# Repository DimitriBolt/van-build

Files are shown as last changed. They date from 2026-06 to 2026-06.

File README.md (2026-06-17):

# van-build — CAD-каркас салона RAM ProMaster 1500 136" High Roof

Параметрическая **каркасная** модель салона кемпера на базе RAM ProMaster 1500
(колёсная база 136", высокая крыша; кузовной близнец — Fiat Ducato L2H2), построенная
во FreeCAD по 3D-скану реального кузова.

## Подход

- **CAD = только каркас** (к нему крепится оборудование). Обшивку в CAD не моделируем.
- **Обшивка = сам 3D-скан** кузова (меш), полупрозрачный, лежит поверх каркаса.
- Внутренний объём — не «коробка», а **сложная форма, снятая со скана**: гнутые борта,
  скруглённое плечо, округлая крыша. Рёбра каркаса — гнутые обручи по контуру скана.

Так совмещаются визуальное сходство (скан) и проектопригодная CAD-геометрия (каркас).

## Система координат

Ноль — пол у порога **задних** дверей, на центральной оси.
`X` = длина (0 сзади, +X к кабине); `Y` = ширина (0 центр, +Y пассажир); `Z` = высота (0 пол).

## Файлы

| Файл | Что это |
|---|---|
| `van_v0.py` | Скрипт-генератор модели (правишь `PARAMS` → пересобираешь) |
| `freecad_rpc.py` | Клиент к живому FreeCAD GUI (`van_rpc_server.FCMacro` на `127.0.0.1:9875`) |
| `van_v0.FCStd` | Собранный документ FreeCAD (каркас + меш-обшивка) |
| `Ducato_L2H2_body_reference.stl` | Чистая наружная оболочка кузова (нужна скрипту) |
| `Ducato+L2H2+lit+superpose2.stl` | Плотный скан целиком (с мебелью/человеком) |
| `Ducato+L2H2+lit+superpose2.skp` | Исходная SketchUp-модель |
| `PROJECT_MEMORY.md` | Сводная память по всему проекту (электрика, кузов, 3D и т.д.) |

## Сборка

Headless:

```bash
~/Applications/FreeCAD.AppImage --console ~/van-build/van_v0.py
```

Скрипт измеряет профиль борта из `Ducato_L2H2_body_reference.stl`, строит каркас,
кладёт скан как обшивку и сохраняет `van_v0.FCStd`.

## Статус

Габариты оболочки и форма свода **измерены по скану**. Точные позиции рёбер, проёмов
дверей и колёсных арок — пока SEED-заглушки; заменяются на реальные значения
после ручного промера фургона (см. раздел про промерку в `PROJECT_MEMORY.md`).

Сторона сдвижной двери задаётся параметром `slider_side` в `van_v0.py`
(`-1` = левый/driver борт `-Y`, `+1` = passenger борт `+Y`); текущая
оценка проёма — `1250 × 1755 мм`.

Текущая модель использует 3 основных гнутых обруча: задняя рама, смещённая внутрь обшивки на X=160, задняя/средняя
рама сдвижной двери и передняя рама сдвижной двери у кабины (`X=1880..3130`, по STL-окну сдвижной двери). Обручи красные,
продольные рейки синие; задняя распашная дверь показана двумя половинками.

Продольные рейки: верхняя поднята до `Z=1700`, средняя оставлена `Z=980`; нижняя `Z=20` показана как низовая крепёжная рейка, касающаяся пола (`Z=0..40`) и разрывается на зоне колёсных арок `X≈520..1650` и сдвижной двери.
Заводские резьбовые точки показаны отдельным слоем `FactoryThreadedMounts`: 3 точки на длинной `pY` рейке `Z=980`, 2 точки на короткой `nY` рейке `Z=980`; текущая память о резьбе — `M8/M10`, надо уточнить промером.

Поперечины пола удалены: в модели вместо них показан рефлёный металлический пол
`CorrugatedFloor` с продольными гребнями вдоль фургона.

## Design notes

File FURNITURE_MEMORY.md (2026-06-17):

# FURNITURE MEMORY — Мебель и подвес оборудования (RAM ProMaster 136 HR)

_Отдельная память по этапу проектирования мебели/крепежа, чтобы не раздувать
`PROJECT_MEMORY.md`. Технические термины/пути — на английском, остальное по-русски.
Источник правды по геометрии кузова — `van_v0.py` / `van_v0.FCStd` (см. `PROJECT_MEMORY.md` §5).
Последнее обновление: 2026-06-17._

---

## 0. Общие принципы этапа
- **Материал каркаса — strut channel (Unistrut/Superstrut/Newhouse)**, покупка Home Depot/Lowe's.
- **БЕЗ СВАРКИ.** Сборка только на fittings: угловые кронштейны 90°, channel nuts (пружинные
  гайки в паз), болты. **Разборная/демонтируемая** — обязательно.
- **Цена важна.** Главное удешевление (2026-06-17): **весь каркас из НЕГЛУБОКОГО профиля**
  (он дешевле всего), а поперечные лаги — из **бесплатных деревянных 2×4** Dimitri.
- Dimitri может **резать strut, сверлить доп. отверстия, нарезать резьбу.**
- Профиль strut: **Неглубокий 1-5/8″×13/16″** (≈41.3×21 мм, 14 ga), сток **10 ft (3048 мм)**.
  ⚠️ Ширина паза 1-5/8″ у неглубокого и глубокого ОДИНАКОВА → **фитинги одни и те же**
  (отличается только глубина спинки). Брать неглубокие фитинги не обязательно — подходят любые.

## 1. Кровать (КАРКАС в `van_v0.py`, группа `Bed_StrutFrame`)
**Тип:** поперечная (спим ПОПЕРЁК фургона), в задней части.
- **ДЛИНА кровати** (вдоль Y, спальное место) = борт↔борт ≈ **1879 мм** (со скана через `y_at_z`).
- **ШИРИНА кровати** (вдоль X, от задних дверей вперёд) — `BED["mattress_width_x"]`,
  **1400 по умолчанию; 1200 — альтернатива.** ⚠️ При **1200** фанера влезает в ОДИН лист
  4×8 (ширина листа 1220 мм) → экономия целого листа. При 1400 нужно 2 листа.
- Верх несущей рамы `BED["top_z"] = 980` ≈ высота заводских резьбовых точек. Под кроватью
  сквозной «гараж» ~0.94 м.

**СХЕМА (удешевлённая, 2026-06-17) — «4 ноги + 2 продольные strut + 2×4-лаги»:**
- **4 ноги-стойки** — неглубокий strut, болтятся к борту в ЗАВОДСКИХ резьбовых точках
  (`FactoryThreadedMounts`, Z=980, резьба **M8/M10 — уточнить на живом фургоне**):
  `pY`/`nY` @ **X=360** (`rear_thread_x`) и `pY`/`nY` @ **X=1680** (`middle_thread_x`).
  Идут от пола Z=0 вверх до **Z≈1330** (плечо крыши) — служат направляющими под обшивку.
  Высота ноги ~1330 < 1524 (5 ft) → **2 ноги выходят из одного 10-ft хлыста**.
- **2 продольные несущие** (вдоль X, Y=±940) — куски **5 ft (1520 мм)**, передним краем к
  X=1720, перекрывают обе ноги; **2 шт из одного 10-ft хлыста** (раскрой 10ft→2×5ft).
- **4 поперечные лаги 2×4** (дерево, БЕСПЛАТНО) — лежат на продольных рейках, на них фанера.
  ⚠️ Пролёт лаги между рейками ~1.8 м: 2×4 **плашмя** может прогибаться. Если просядет —
  поставить 2×4 **на ребро** (89 мм по высоте) или добавить центральную балку. См. §3.
- **Настил — фанера 1/2″** (дешевле 3/4″) на лагах; задний край свешивается ~180 мм за рейку
  (консоль фанеры — нормально, опор не нужно). Матрас — **поролон, режется по форме**.
- **РАСКРОЙ strut: ровно 3 хлыста ×10ft = 4 ноги (2 шт/хлыст ×2) + 2 продольные (1 хлыст).**

**Что УБРАЛИ при удешевлении (2026-06-17):**
- 5-я стойка под оборудование (`equip_post=False`) — ОТЛОЖЕНА (не входит в 3 хлыста; вернуть = `True`).
- Задние опорные ножки на полу — не нужны (свес фанеры всего ~180 мм).
- Глубокий профиль и неглубокие поперечины strut — заменены неглубоким каркасом + 2×4.

**РЕШЕНО ранее (2026-06-16): стойки обрезаются на плече крыши ≈ Z=1330, до потолка НЕ ведём**
(прямой вертикальный strut на Y≈940 выше Z≈1330 вышел бы наружу сквозь скан — крыша
заворачивает внутрь). `post_top` считается авто как макс. Z, где `y_at_z(z) >= yL`.

**Смета — см. §4. Текущая оценка ~$165** (strut $69 + крепёж $32 + фанера+саморезы $64,
цена за единицу). В магазине наборами/упаковками — реально **~$190–200** (или ~$170 при ширине
1200 / 1 лист; ~$140 если настил из своих 2×4 без фанеры). Без поролона.

**Совместимость с проёмами:** кровать целиком ПОЗАДИ сдвижной двери; ноги X=360/1680 не в
проёмах. Под кроватью загрузка через задние двери.

## 2. Где это в коде
- `van_v0.py`: `BED = {...}` и `BED_PRICES = {...}` под `PARAMS`; построение — секция
  «КРОВАТЬ — каркас из strut channel» в `build()` (группа `Bed_StrutFrame`); смета печатается
  в сводке. Цвета: `COL_STRUT` (сталь), `COL_PLY` (фанера), `COL_WOOD` (2×4), `COL_MATTRESS`.
- Объекты: `BedLeg_*` (4 ноги), `BedRailLong_*` (2 продольные), `BedJoist2x4_*` (4 лаги),
  `BedDeck_Plywood`, `BedMattress`.
- Пересборка headless: `~/Applications/FreeCAD.AppImage --console ~/van-build/van_v0.py`.
  Цвета/рендер — только пересборкой в живом GUI через RPC (см. [[freecad-snap-live-control]]).
- Параметры под изменение: ширина `mattress_width_x` (1400↔1200), `n_joist`, `deck_th`,
  `equip_post`, `rail_len`.

## 3. Открытые вопросы / ждёт живого фургона
- [ ] Решить ширину кровати вдоль X: **1200 (1 лист фанеры, дешевле)** или **1400**.
- [ ] Уточнить заводскую резьбу в точках Z=980: **M8 или M10**, и реальные X/Z точек.
- [ ] **Проверить прогиб лаг 2×4 плашмя на пролёте ~1.8 м** под спальной нагрузкой.
      Если есть прогиб: (а) 2×4 на ребро, (б) больше лаг, (в) центральная продольная балка
      на 2 напольных стойках. Дерево бесплатное → дёшево усилить.
- [ ] Финальный замер длины борт↔борт и высоты ноги на живом фургоне → подрезка.

---

## 4. СПИСОК ПОКУПОК (BOM) — открой в магазине, ничего не забудь
_Цены США, июнь 2026 (проверять при заказе). Можно из РАЗНЫХ магазинов. Поролон НЕ входит._
_Считается на ширину 1400 мм (2 листа фанеры). Для 1200 мм — 1 лист (−$28)._

### A. Strut channel — Home Depot (самовывоз; длинномер дорого слать)
- [ ] **Неглубокий strut 1-5/8″×13/16″ 14ga 10 ft** — Newhouse **SC14-10-EG**, **$23/шт × 3 = $69**.
  - Раскрой: хлыст №1 → 2 ноги (~1330 мм); хлыст №2 → 2 ноги; хлыст №3 → 2 продольные (1520 мм).

### B. Фитинги (Amazon оптом дешевле; берём упаковками)
- [ ] **Уголок 90° для strut (2-отв.)** — нужно **4 шт**. Мультипак ~$12–15.
- [ ] **Пружинная гайка + болт 1/2″-13 (channel nut + bolt)** — нужно **~16 компл.**
  Брать **набор 50 шт ~$30–40** (хватит с запасом на оборудование позже).
- [ ] **Болт в заводскую резьбовую точку борта (M8 или M10 — уточнить!)** — **4 шт**, ~$5.
- [ ] **Заглушки на торцы strut** — **~12 шт**, пакет 25 ~$8.

### C. Дерево — БЕСПЛАТНО (из запасов Dimitri)
- [ ] **2×4 длиной ~1.9 м — 4 шт** (поперечные лаги под фанеру). $0.

### D. Настил
- [ ] **Фанера 1/2″ 4×8 ft** — CDX ~$28/лист (OSB ~$18 ещё дешевле).
  **2 листа** при ширине 1400 = ~$56. **1 лист** при ширине 1200 = ~$28.
  ⚠️ Альтернатива «настил из 2×4-реек» (свои, $0) — фанера не нужна вообще, минус ~$56.
- [ ] **Саморезы по дереву (коробка)** ~$8.

### E. Поролон (отдельно, режет сам) — НЕ в этой смете
- [ ] Поролон под матрас ~$80–150 (Amazon/магазин поролона), режется по форме.

### ИТОГ (без поролона)
| Вариант | Цена |
|---|---|
| Базовый (ширина 1400, фанера 2 листа) | **~$190–200** |
| Ширина **1200** (фанера 1 лист) | **~$165–175** |
| Настил из своих 2×4-реек (без фанеры), ширина 1200 | **~$140** |

_Оценка в коде (`van_v0.py`, цена за единицу) ~$165; разница с «магазинной» — из-за упаковок
(гайки набором 50, уголки мультипаком). Брать наборы выгодно — пригодятся под оборудование._

### Совместимость фитингов (проверено)
Все соединения — **стандартные, спец-деталей нет**:
- нога ↔ борт: болт через паз strut в заводскую резьбу (+ пружинная гайка при нужде);
- нога ↔ продольная рейка (угол 90°): уголок + 2 пружинные гайки + 2 болта;
- лага 2×4 ↔ продольная рейка: пружинная гайка в паз + болт/глухарь снизу вверх в дерево;
- 2×4 ↔ фанера: саморезы по дереву.
Неглубокий профиль принимает те же фитинги, что и глубокий (паз 1-5/8″ одинаков).

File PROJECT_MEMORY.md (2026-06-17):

# PROJECT MEMORY — Постройка автодома на базе Ram ProMaster

_Последнее обновление: 2026-06-16. Единый источник правды по проекту для Dimitri, Claude (чат) и Claude Code. Держать в `~/van-build/` (репозиторий проекта). Технические термины/пути — на английском, остальное по-русски._

---

## 1. Автомобиль (КРИТИЧНО: это НЕ Ram 1500 пикап!)
- **Модель:** 2014 RAM 1500 ProMaster Cargo, колёсная база 136", высокая крыша (High Roof).
- **VIN:** см. локальный `vehicle-private.md` (в `.gitignore`, не публикуется)
- **Двигатель:** 3.6L V6 24V VVT (бензин)
- **КПП:** 6-ступенчатый автомат 62TE
- **Помнить всегда:**
  - ProMaster 1500 — перелицованный Fiat Ducato (L2H2). **Информацию о Ram 1500 (пикап) НЕЛЬЗЯ переносить на ProMaster** — это совершенно разные машины.
  - Кузов **несущий (unibody/monocoque)**, не рамный.
  - Машина — одновременно транспорт и **постоянное жильё** (full-time). Приоритеты: надёжность, автономность, комфорт важнее цены.
  - Системный подход: всё проверяется по первоисточникам (мануалы, форум, видео производителя).

## 2. Сообщество и магазины
- **Форум:** https://www.promasterforum.com/ (основной по ProMaster)
- **Facebook-группа:** https://www.facebook.com/groups/140882716333661
- **Покупки (по приоритету):** Amazon.com или Temu -> реже Home Depot -> ещё реже Lowe's -> последний вариант Walmart.
- Ковры/остатки покрытий брать у локальных независимых магазинов напольных покрытий, не в больших сетях (там бесплатных остатков обычно нет).

## 3. Электрооборудование (ВАЖНО: пока НИЧЕГО не установлено — всё на этапе выбора/плана)

**Выбрано и подтверждено:**
- **Головное устройство:** XISEDO 9", Android 13 (4/64 ГБ), ProMaster-специфичная CAN-bus интеграция; поддержка нескольких камер, TPMS, OBD2. SIM **T-Mobile** уже куплена.
- **Зеркало-видеорегистратор:** RoadWitness 12", 3-канальный, Sony STARVIS 2 IMX675. Даёт ADAS, частично заменяет отдельный регистратор.
- **Навигационный дисплей:** широкоформатный 11.5" CarPlay/Android Auto (Amazon ASIN **B0GLFSD2DD**), ставится прямо перед водителем (минимум перекрытия обзора).
- **Контроль слепых зон (BSD):** комплект EchoMaster **FCTP-DP1504** (ProMaster-специфичные накладки зеркал с камерами) через коммутатор PAC **VS41**, срабатывание по поворотникам. (Альтернатива в проработке: радар EASYGUARD **EBS001** — монтируется ВЕРТИКАЛЬНО, большой плоской гранью назад/наружу, за пластиком бампера.)
- **OBD-диагностика:** адаптер **OBDLink MX+** + AlfaOBD (дилерский уровень) + Torque Pro (живой дашборд на XISEDO) + OBD Fusion. Для 2014 г. **обход Security Gateway не нужен** (SGW появился с 2018).
- **TPMS:** Tymate **TM7** с внешними датчиками.
- **Парктроники:** EKYLIN, 8 ультразвуковых датчиков, вывод по RCA на экран головного устройства (без отдельного дисплея).
- **Конфликт OBD-порта:** Y-сплиттер (~$10–15), чтобы делить порт между OBDLink MX+ и ADAS-регистратором.

**Аккумулятор:** выбран в **Walmart**. [Уточнить конкретную модель/тип/ёмкость — точной модели в памяти нет, впиши сюда.]

**Открытые вопросы по электрике:**
- **LTE-антенна (2x2 MIMO):** ждём подтверждения, сколько SMA-портов у XISEDO (один или два), прежде чем покупать.
- **Thinkware U3000 2CH:** под вопросом. RoadWitness уже закрывает ADAS/запись; ключевое отличие U3000 (аппаратный 24 ГГц радар для безопасного для АКБ режима парковки) менее критично при постоянном проживании в фургоне.

**Порядок установки (план):** XISEDO -> камера заднего вида -> парктроники -> накладки EchoMaster -> зеркало RoadWitness -> проводка Thinkware (если купит) -> TPMS -> OBD2 -> LTE-антенна в самом конце. После установки — обязательная калибровка ADAS в приложении Thinkware.

## 4. Структурные/кузовные работы
- **Дверной ограничитель (door check):** Mopar **68169379AE**. Точка крепления треснула, но металл цел. Ремонт: усиливающая пластина (Support Plate) **68367425AA**, заводится через отверстие динамика и заводское овальное технологическое отверстие у A-стойки, фиксируется U-образным кронштейном; трещину сначала проклеить эпоксидкой. На ProMaster ограничитель держит ВСЮ нагрузку открытой двери (петли не дают стопора) — известное слабое место.
- **Пол:** слоёный пирог **XPS-пена -> фанера -> финишное покрытие** (против конденсата/плесени/ржавчины). Ковёр прямо на металл класть нельзя — копит конденсат.

## 5. 3D-модель салона (FreeCAD)
**Цель:** модель интерьера с точностью до мм для раскроя панелей; шкафы по кривым стенкам.

**Окружение / тулчейн:**
- Ubuntu 26.04 (KDE/X11), ноутбук Dell M6800. Каталог проекта: **`~/van-build`**. На 2026-06-16 каталог уже является git-репозиторием; `van_v0.py`, `van_v0.FCStd`, `PROJECT_MEMORY.md`, `README.md` отслеживаются git.
- **FreeCAD: AppImage 1.1.1** (x86_64, py311), лежит в **`~/Applications/FreeCAD.AppImage`**, ярлык в меню `~/.local/share/applications/freecad.desktop` (Terminal=false).
  - Ушли со snap: snap блокировал `/run/spnav.sock` (3D-мышь не видна) и подменял `$HOME` (ломало MCP-workflow). Flatpak тоже отвергли (та же песочница). AppImage — без песочницы, работает и 3D-мышь, и MCP.
- **Модель:** `~/van-build/van_v0.py` -> `van_v0.FCStd`. Числовые размеры SEED остаются заглушками; реальная форма кузова теперь добавлена отдельным STL/reference-слоем.
  - 2026-06-15: `van_v0.py` детализирован и пересобран через `~/Applications/FreeCAD.AppImage --console van_v0.py`; текущий `van_v0.FCStd` после правок 2026-06-16 содержит 63 Part-объекта и 1 Mesh-объект.
  - Добавлено как SEED/reference: арочные колёсные арки вместо прямоугольных, горизонтальные рейки стен (`WallRail_*`, с разрывом на +Y по сдвижной двери), рефлёный пол (`CorrugatedFloor`, продольные гребни вдоль X), верхние продольные рейки (`RoofLongitudinal_*`), зоны хода задних/сдвижной дверей, грубая reference-кабина и контрольные поперечные сечения `Measurement_Sections`.
  - Overall bbox текущего документа с full-body STL/reference-зонами: примерно **5562 × 2074 × 2102 мм**; длина/высота теперь включают внешний body-only STL, задние двери наружу по -X и кабину по +X.
- **Система координат:** origin = пол на пороге ЗАДНИХ дверей по центральной оси. X = длина (0 сзади, +X к кабине), Y = ширина (0 по центру, +Y к пассажиру), Z = высота (0 пол, +Z вверх).

**Подключение к MCP-серверу FreeCAD (для Claude Code):**
- Схема: аддон **freecad-mcp** в `~/.local/share/FreeCAD/Mod/` поднимает RPC-сервер внутри FreeCAD; Claude Code подключается к нему как MCP-клиент (запись в конфиге MCP Claude Code).
- После перехода snap -> AppImage **аддон нужно переустановить** в `~/.local/share/FreeCAD/Mod/` (в snap-каталоге он стёрся при `snap remove freecad`). Файлы `van_v0.*` в `~/van-build` не пострадали.
- [Точные детали — репозиторий аддона, имя команды запуска RPC-сервера, адрес/порт и блок в конфиге Claude Code — переустановить и зафиксировать ЗДЕСЬ при возобновлении моделирования. Claude Code: впиши реальные значения из системы.]
- 2026-06-16: в системе найден макрос `~/.local/share/FreeCAD/Macro/van_rpc_server.FCMacro`, который поднимает XML-RPC на `127.0.0.1:9875` (`ping`, `execute_code`, `save_screenshot`). Для Codex добавлен клиент `~/van-build/freecad_rpc.py`; prefix rule `["python3", "freecad_rpc.py"]` одобрен, поэтому Codex может выполнять код в живом FreeCAD GUI и сохранять скриншоты без повторных approval prompts. Глобальный `~/.codex/config.toml` возвращён на `approval_policy = "on-request"`: sandbox остаётся включённым, но Codex может запрашивать точечный unsandboxed-доступ для loopback/RPC.

**Поиск готовой 3D-модели/скана — итог:**
- Точного бесплатного твердотельного CAD ProMaster НЕ существует.
- Найдено и скачано: модель GrabCAD «136 HR camper» — это **SketchUp `.skp` (меш)**, с мебелью (нары), не его фургон; FreeCAD `.skp` не импортирует. Локальные файлы: `~/van-build/Ducato+L2H2+lit+superpose2.skp` и ZIP `~/van-build/fiat-ducato-ram-promaster-136-wheel-base-high-roof-camper-conversion-1.snapshot.1.zip`; ZIP содержит тот же `.skp`.
- 2026-06-15: попытка извлечь из `.skp` текстовые метаданные (`file`, `strings`, `rg -a`) не дала надёжной измеряемой геометрии: видны только бинарные SketchUp-сущности/материалы, но не пригодные координаты рёбер/отверстий. Без SketchUp-импортера считать этот файл источником точных CAD-данных нельзя.
- 2026-06-15: использован экспортированный/полученный STL `~/van-build/Ducato+L2H2+lit+superpose2.stl` (binary SketchUp STL, header `SketchUp STL tmpkneDIP`). Вся сцена: 154 589 треугольников, общий bbox около **5836 × 4027 × 2560 мм**; в сцене есть кузов, человек и внутренняя мебель/модель.
- 2026-06-15: из STL выделен крупнейший связный компонент как кузов без человека/мебели: `~/van-build/Ducato_L2H2_body_reference.stl`, 16 283 треугольника, bbox около **5402 × 2068 × 2102 мм**. Y центрируется на ось 0; X/Z оставлены как в STL (пол около Z=0, задняя часть кузова уходит в -X).
- 2026-06-15: `van_v0.py` теперь добавляет `Scan_Reference/STL_Body_Reference` как `Mesh::Feature` и строит `Scan_Reference/STL_Derived_Sections` — реальные поперечные `Part`-полилинии из STL в X-точках `[0, 400, 920, 1440, 1960, 2480, 3000, 3120]`. Это делает `van_v0.FCStd` визуально ближе к реальному ProMaster/Ducato и даёт рабочие контуры для сравнения с SEED-сечениями.
- Ограничение: STL/reference — это меш, не параметрический solid. Для раскроя мебели его можно использовать как форму/контур, но заводские рёбра, отверстия, внутренние крепёжные точки и точные панели всё равно надо переводить в параметрическую геометрию и проверять ручными промерами.
- 2026-06-16: без живого фургона обновили `van_v0.py`/`van_v0.FCStd`: сдвижной проём и разрыв продольных реек перенесены на левый/driver борт `-Y` через параметр `slider_side = -1`. Размер проёма оставлен `1250 × 1755 мм` как текущая Ducato/ProMaster reference-оценка; ручной промер обязателен. Если выяснится, что конкретная машина имеет passenger-side дверь, переключить `slider_side` на `+1`.
- 2026-06-16: поперечины пола удалены как неверная конструктивная сущность; вместо них добавлен `CorrugatedFloor` — 17 продольных гребней рефлёного пола вдоль X, шаг ~115 мм и высота ~8 мм, визуально как профнастил C-8. Каркас визуально упрощён до 3 основных гнутых обручей `Rib_x0160`, `Rib_x1880`, `Rib_x3130`: задняя рама распашной двери смещена внутрь обшивки на X=160, задняя/средняя рама сдвижной двери и передняя рама сдвижной двери у кабины; позиции `1880..3130` подобраны по STL-окну на сдвижной двери (`X≈1960..3066`). Цвета разведены для чтения модели: обручи красные, продольные рейки синие. Задняя распашная дверь добавлена как две симметричные reference-створки `RearDoorLeaf_Driver` и `RearDoorLeaf_Passenger`.
- 2026-06-16: продольные рейки уточнены по памяти: верхняя рейка поднята до `Z=1700`, средняя оставлена `Z=980`, нижняя `Z=20` теперь считается низовой крепёжной рейкой для связки вертикальной боковой обшивки с полом; при сечении 40 мм она занимает `Z=0..40` и касается пола. Нижняя рейка разрывается на зоне задних колёсных арок `X≈520..1650` на обоих бортах и на сдвижной двери `X=1880..3130` на левом/driver борту; короткие хвостики меньше 180 мм не рисуются.
- 2026-06-16: добавлен отдельный слой `FactoryThreadedMounts` для 5 заводских резьбовых точек на средней рейке `Z=980`: `pY` получает 3 точки (`X≈360`, `X≈1680`, `X≈2930`), `nY` получает 2 точки (`X≈360`, `X≈1680`). Логика: 2 точки примерно на 200 мм вперед от заднего ребра `Rib_x0160`, 2 точки примерно на 200 мм назад от среднего ребра `Rib_x1880`, пятая точка на длинной `pY` рейке примерно на 200 мм назад от переднего ребра `Rib_x3130`. Резьба по памяти `M8/M10`, обязательно уточнить на живом фургоне.
- 2026-06-15: дополнительный web-поиск подходящих 3D-сканов/моделей именно **Ram ProMaster 1500 136 High Roof / Fiat Ducato L2H2** не дал нового пригодного источника. Находки по 159 WB / ProMaster 2500 / длинным Ducato/Boxer/Jumper не подходят для точной CAD-базы. Внешние источники подтверждают только общее родство Ducato и ProMaster и различие wheelbase-вариантов, но не дают точный интерьерный скан.
- Платные модели — рендер-меши, отвергнуты. Сканы чужих машин использовать только как визуальный reference; сверка пары размеров проверяет масштаб, но не локальные рёбра/отверстия.
- **Вывод:** body-only STL теперь полезен как визуальный/контурный reference формы кузова; источник правды для крепежа, рёбер, отверстий и миллиметровых внутренних размеров всё равно реальный фургон, промеряем руками. Текущая детализация `van_v0` — рабочая база для сравнения и дальнейшей параметризации, не финальная производственная геометрия.

**План ручной промерки (когда фургон вернётся из сервиса):**
- Измерить реальные позиции рёбер/стоек/порогов/дуг крыши, заводские отверстия, геометрию дверей, кривизну стенки (картонный шаблон), интерьер от ГОТОВОГО пола (XPS+фанера).
- Заменить SEED-значения в PARAMS `van_v0.py`.
- Заменить SEED/reference-детализацию 2026-06-15 на реальные измерения: горизонтальные рёбра, кабину, двери/зоны хода, рефлёный пол, верхние рейки и контрольные сечения.
- Затем — раскладка мебели по реальной структуре.
- Факты с форума: обрешётка крепится ТОЛЬКО к рёбрам, не к обшивке; глубина ребра 25–75 мм по высоте; заводские шестигранные отверстия в боковых рёбрах под ривнаты.

## 5a. Мебель / подвес оборудования
- Этап начат 2026-06-16. **Память по мебели/крепежу вынесена в отдельный файл `FURNITURE_MEMORY.md`** (чтобы не раздувать этот), там — кровать из strut channel, заводские точки крепления, смета.
- Кратко: поперечная кровать в задней части на strut channel (Unistrut/Superstrut, Home Depot/Lowe's), БЕЗ сварки, разборная, ноги в 4 заводские резьбовые точки Z=980 (X=360/1680) + 5-я стойка под оборудование (pY X=2930). Построена в `van_v0.py`, группа `Bed_StrutFrame`.

## 6. 3D-манипулятор (3Dconnexion SpaceExplorer) в FreeCAD
- Устройство: 3Dconnexion SpaceExplorer, USB **046d:c627**.
- Драйвер: **spacenavd 1.3.1** из apt (`systemctl enable --now spacenavd`), сокет `/run/spnav.sock`.
- В snap-FreeCAD мышь не видна (песочница режет сокет) -> решилось переходом на AppImage.
- **Кнопки настраивать ТОЛЬКО правкой `user.cfg`**, не через диалог Customize -> «Кнопки пространственного манипулятора» (баг FreeCAD **#17812** — путает активную кнопку; «Сброс» тоже багован — **#19366**, не использовать).
  - Файл: `/home/dimitri/.config/FreeCAD/v1-1/user.cfg`, группа `Spaceball/Buttons`.
  - **Нумерация: в файле Button 0-based, в GUI «Кнопка N». Индекс в файле = (Кнопка N) минус 1.**
  - **FreeCAD должен быть ЗАКРЫТ при правке** (он переписывает `user.cfg` при выходе). Сначала бэкап.
  - Имена команд: `Std_ViewFitAll`, `Std_ViewFront`, `Std_ViewTop`, `Std_ViewRight`, `Std_ViewLeft`, `Std_ViewRear`, `Std_ViewBottom`, `Std_ViewIsometric`.
- **Текущий маппинг кнопок** (физическая -> GUI Кнопка -> file Button -> команда):
  - FIT  -> Кнопка 11 -> Button 10 -> `Std_ViewFitAll`
  - T    -> Кнопка 3  -> Button 2  -> `Std_ViewTop`
  - F    -> Кнопка 6  -> Button 5  -> `Std_ViewFront`
  - R    -> Кнопка 5  -> Button 4  -> `Std_ViewRight`
  - L    -> Кнопка 4  -> Button 3  -> `Std_ViewLeft`
  - 2D   -> Кнопка 15 -> Button 14 -> `Std_ViewIsometric`
- Движение: режим «Доминирующий режим» (Dominant) включён.

## 7. Среда / прочее
- Раскладку клавиатуры Dimitri переключает **Win+Space** (RU/EN).
- Язык общения по проекту — русский.

---

## TODO / открытые пункты
- [ ] Вписать конкретную модель аккумулятора (Walmart).
- [ ] Подтвердить число SMA-портов XISEDO -> купить LTE-антенну (2x2 MIMO).
- [ ] Решить по Thinkware U3000.
- [ ] Переустановить аддон freecad-mcp в `~/.local/share/FreeCAD/Mod/`; зафиксировать точную MCP-конфигурацию здесь.
- [x] Вписать точный путь к скачанной модели GrabCAD `.skp`: `~/van-build/Ducato+L2H2+lit+superpose2.skp`.
- [ ] По `STL_Derived_Sections` обвести/заменить SEED-оболочку на реальные параметрические профили кузова, затем проверить масштаб/позицию по ручным замерам.
- [ ] Когда вернётся фургон — ручная промерка, заменить SEED в `van_v0.py`, особенно горизонтальные рёбра/кабину/двери/пол/верхние рейки.
- [ ] Проверить, почему `~/van-build` сейчас не виден как git-репозиторий, хотя память проекта раньше считала его git-папкой.
- [ ] Ремонт дверного ограничителя (68169379AE + пластина 68367425AA).
- [ ] Пол: XPS -> фанера -> финиш.

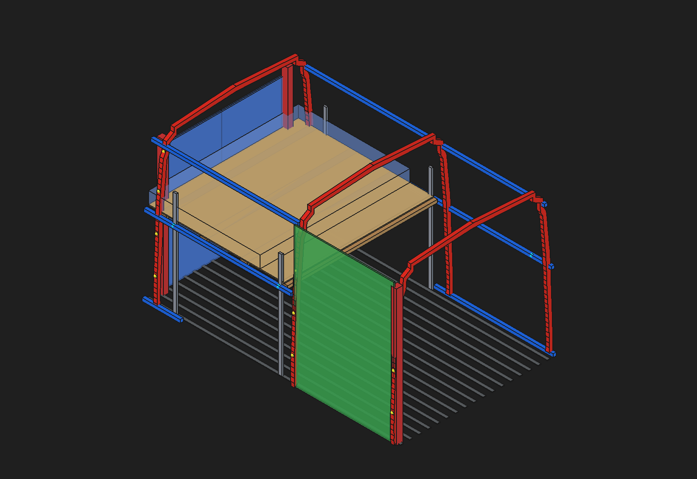
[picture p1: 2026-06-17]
render_bed_cheap.png

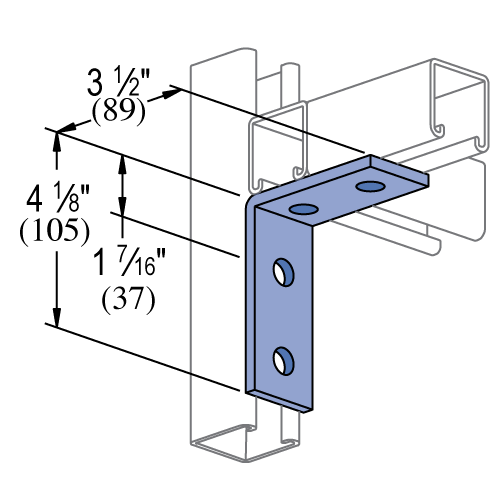
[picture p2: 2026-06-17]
p1325_500x.png

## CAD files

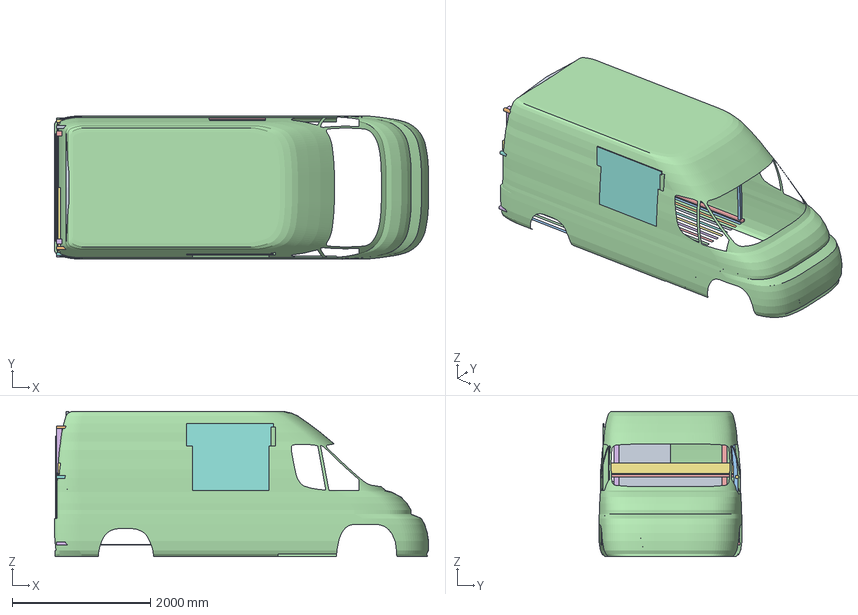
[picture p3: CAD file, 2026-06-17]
van_v0.FCStd
5402.3 x 2068.3 x 2101.5 mm
Ребро X=160 — задняя рама распашной двери, смещена внутрь обшивки
Ребро X=1880 — задняя/средняя рама сдвижной двери по окну STL
Ребро X=3130 — передняя рама сдвижной двери у кабины по окну STL
Рейка pY (противоположный борт) Z=20 сегм.1
Рейка pY (противоположный борт) Z=20 сегм.2
Рейка nY (борт сдвижной двери) Z=20 сегм.1
Рейка pY (противоположный борт) Z=980 сегм.1
Рейка nY (борт сдвижной двери) Z=980 сегм.1
Рейка pY (противоположный борт) Z=1700 сегм.1
Рейка nY (борт сдвижной двери) Z=1700 сегм.1
Продольный гребень пола Y=-931.34
Продольный гребень пола Y=-816.34
Продольный гребень пола Y=-701.34
Продольный гребень пола Y=-586.34
Продольный гребень пола Y=-471.34
Продольный гребень пола Y=-356.34
Продольный гребень пола Y=-241.34
Продольный гребень пола Y=-126.34
Продольный гребень пола Y=-11.3401
Продольный гребень пола Y=103.66
Продольный гребень пола Y=218.66
Продольный гребень пола Y=333.66
Продольный гребень пола Y=448.66
Продольный гребень пола Y=563.66
Продольный гребень пола Y=678.66
Продольный гребень пола Y=793.66
Продольный гребень пола Y=908.66
B-стойка (перед сдвижного проёма, -Y)
Задняя стойка pY (край проёма X=0)
Задняя стойка nY (край проёма X=0)
Точка pY X=160 Z=350
Точка nY X=160 Z=350
Точка pY X=160 Z=800
Точка nY X=160 Z=800
Точка pY X=160 Z=1250
Точка nY X=160 Z=1250
Точка pY X=160 Z=1650
Точка nY X=160 Z=1650
Точка pY X=1880 Z=350
Точка nY X=1880 Z=350
Точка pY X=1880 Z=800
Точка nY X=1880 Z=800
Точка pY X=1880 Z=1250
Точка nY X=1880 Z=1250
Точка pY X=1880 Z=1650
Точка nY X=1880 Z=1650
Точка pY X=3130 Z=350
Точка nY X=3130 Z=350
Точка pY X=3130 Z=800
Точка nY X=3130 Z=800
Точка pY X=3130 Z=1250
Точка nY X=3130 Z=1250
Точка pY X=3130 Z=1650
Точка nY X=3130 Z=1650
Заводская резьбовая точка pY, M8/M10 (уточнить), около 200 мм вперед от заднего ребра
Заводская резьбовая точка nY, M8/M10 (уточнить), около 200 мм вперед от заднего ребра
Заводская резьбовая точка pY, M8/M10 (уточнить), около 200 мм назад от среднего ребра
Заводская резьбовая точка nY, M8/M10 (уточнить), около 200 мм назад от среднего ребра
Заводская резьбовая точка pY, M8/M10 (уточнить), около 200 мм назад от переднего ребра; только длинная рейка
Нога кровати strut pY X=360 (болт к борту Z=980, до Z=1330)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

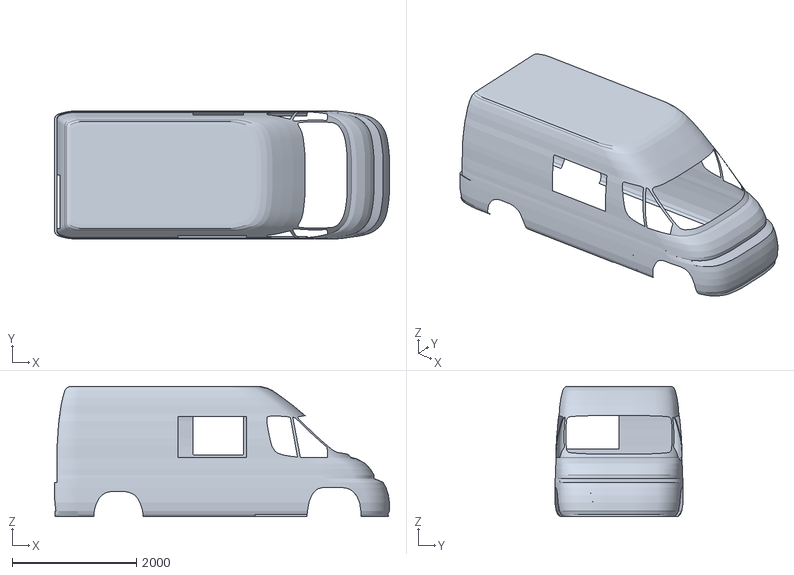
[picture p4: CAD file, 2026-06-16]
Ducato_L2H2_body_reference.stl
5402.3 x 2068.3 x 2101.5

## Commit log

2026-06-16 Каркасная CAD-модель салона ProMaster 136 HR по 3D-скану
    - van_v0.py: каркас (гнутые рёбра-обручи по профилю скана), скан как
    полупрозрачная обшивка поверх каркаса; профиль измеряется из
    Ducato_L2H2_body_reference.stl, выровненного в СК модели.
    - van_v0.FCStd: собранный документ (каркас + меш-обшивка).
    - README.md, PROJECT_MEMORY.md, исходные сканы (STL/SKP).
    [Ducato_L2H2_body_reference.stl, van_v0.FCStd]
2026-06-17 Каркас кровати из strut channel + автозапуск FreeCAD RPC
    Этап мебели: поперечная кровать в задней части на strut channel
    (Unistrut/Superstrut), без сварки, разборная.
    - 4 ноги-стойки в заводские резьбовые точки Z=980 (X=360/1680) +
    5-я стойка под оборудование (pY X=2930); стойки обрезаны на плече
    крыши Z≈1330 (прямой профиль до потолка не доходит из-за кривизны).
    - Продольные несущие + неглубокие поперечины под фанеру, матрас;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
    [van_v0.FCStd]
2026-06-17 Кровать: настил до задней двери + задние ножки; честная смета по ценам
    - BED["deck_rear_x"]=20 — настил/продольные/задняя поперечина тянутся почти
    до задней двери (X≈0), по просьбе; передний край = bed_cx + ширина/2.
    - 2 задние опорные ножки на полу (BedRearFoot_*) под свес настила за ноги.
    - Смета переписана: упаковка по 10-фт хлыстам (FFD, длинные ~1.8 м куски
    дают 1 шт/хлыст) + реалистичный счёт крепежа; раздельн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
    [van_v0.FCStd]
2026-06-17 Кровать: удешевление до ~$165 — весь каркас из неглубокого strut + 2×4-лаги
    - Весь каркас из неглубокого 1-5/8×13/16 14ga (Newhouse SC14-10-EG $23/10ft),
    ровно 3 хлыста: 4 ноги (~1330) + 2 продольные 5ft (1520).
    - Поперечные лаги — бесплатные 2×4 (4 шт) вместо strut-поперечин.
    - Фанера 1/2" вместо 3/4"; ширина 1200 → 1 лист.
    - Убраны 5-я стойка оборудования (отложена) и задние ножки (свес ~180мм).
    - BOM-список покупок (A–E) + совместимость фити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
    [van_v0.FCStd]
2026-11-06 Стороны +Y/−Y: исправлены подписи; скрипты сборки и рендера
    - Подписи сторон приведены к правой СК FreeCAD: +Y = левый борт (водитель),
    −Y = правый борт (пассажир, штатная сдвижная дверь). Геометрия не менялась:
    slider_side = -1 был верным, ошибочными были только подписи и совет
    «переключить на +1» в PROJECT_MEMORY.md.
    - RearDoorLeaf_Driver/_Passenger поменяны местами, чтобы имя совпадало
    со стороной (вместе дают тот же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
2026-11-06 FURNITURE_MEMORY: реальная кровать — реконструкция размеров по 16 фото
    Профиль подтверждён по наклейке: Newhouse SC14-10-EG (1-5/8 x 13/16, 14 ga,
    прорези 9/16 x 1-1/8 с шагом 2"). Высоты посчитаны по прорезям стоек:
    продольная рейка ~680 мм (центр), верх настила ~720 мм, болт в кузов ~760 мм.
    Модель van_v0.py пока не менялась.
    Claude-Session: https://claude.ai/code/session_01DPoggcp9it7RUBK3SUhpuu
2026-11-06 Модель: реальная кровать по фото + пол XPS/фанера + колёсные арки
    - BED переписан под построенную кровать (реконструкция по 16 фото):
    4 стойки SC14-10-EG на пластинах (X=370/1587), болт в кузов ~762 мм,
    продольные рейки по бортам, 3 съёмные поперечины, настил MR ~19 мм
    (1220 вдоль X), матрас 100 мм, на борту -Y стеновая фанера + 2x4.
    Высоты BED[*_h] — от верха напольной фанеры.
    - FLOOR: XPS FOAMULAR NGX F-150 1" + фанера 1/2" (чистовой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
2026-11-06 Арка по Upfit Supply + стойки от арки по фото 2; батарея 150Ah в карман не влезает
    - WHEEL_ARCH: кожух сужается от стены (35", Upfit Supply) к внутренней
    грани (29.8", рулетка фото 2), высота 17"; loft двух полуэллипсов.
    - BED: X стоек выводятся от арки — зазор по полу до внутренней грани
    арки 196 мм сзади и 180 мм спереди (поперечные полосы пола переносят
    рулетку на стену). Шаг стоек 1174 = 1220 - 41: настил перекрывает стойки.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
2026-11-06 FURNITURE_MEMORY: батарея между D-стойкой и аркой — впритык, что промерить
    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
2026-11-06 Этажерка под 2 батареи Buknuwo 150Ah между D-стойкой и аркой (борт -Y)
    - BATTERY_RACK: нижняя батарея узкой стороной вдоль борта, задом в
    D-стойку, прижата к стойке кровати (зазор до арки ~2 мм); новая стойка
    P2 у борта (как задняя, болт к продольной рейке кровати), короткие P3/P4
    со стороны салона, полка: 2 рейки strut + фанера 1/2", верхняя батарея.
    - Реф-грань D-стойки (скос к центру — SEED). Арка у стены 34.6".
    - Свод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
2026-11-06 Этажерка: верхние стяжки, P2 в кузов (M6), кровать +1"
    - BATTERY_RACK.top_ties: стяжки P1-P3 и P2-P4 над верхней батареей
    (630..671 мм над полом), P3/P4 доведены до стяжек (669 мм).
    - P2: болт в ребро кузова на высоте заводской M8 у P1 (новая резьба M6).
    - BED.rail_raise = 25.4: кровать на 1" выше, чтобы прошли стяжки
    (до низа реек 14 мм); брус 2x4 остаётся на прежней высоте.
    - FURNITURE_MEMORY §1b: решения Dimitri, надёжность, раскрой (2 хлыста).
    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
2026-11-06 Этажерка: верхние стяжки = поперечины кровати, без подъёма кровати
    - BATTERY_RACK.top_ties = "bed": задняя стяжка — существующая BedCross_1
    (P3 по X как P1), передняя — новая поперечина BedCross_RackFront перед
    P4 на всю ширину (front_cross_full). P3/P4 до уровня поперечин (699 мм).
    - BED.rail_raise = 0: подъём на 1" больше не нужен; до верхней батареи 68 мм.
    - Режим "short" (отдельные стяжки над батареей) оставлен параметром.
    - render_views: вид rack_wit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
2026-11-06 Этажерка утверждена: упор полки, резиновый брусок, список покупок
    - BATTERY_RACK: упор-уголок по переднему краю полки (держит верхнюю
    батарею вперёд) и резиновый брусок над нижней батареей.
    - Группа BatteryRack помечена «УТВЕРЖДЕНО 2026-11-06».
    - FURNITURE_MEMORY §1b: перечень объектов модели и что купить.
    - Чертёж обновлён.
    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
2026-11-08 Рейка этажерки у борта — сквозным болтом через стойки кровати (как рейка кровати); короткие Label + Label2; начальный вид
    - BankRail_Wall: X 357..1572 по грани стоек P1/Pf со стороны салона, болты 3/8″ BankRailBolt_P1/Pf (без уголков);
    поперечины лестницы 173 мм между рейками; резина на арке — под рейкой
    - short_labels(): в Label — короткое название (≤45, дубли #2), полное описание — в Label2; USER_NOTES сохраняет
    заметки Dimitri (BankRail_Wall)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
2026-11-09 Исправил руками порядок в assembly.py
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
